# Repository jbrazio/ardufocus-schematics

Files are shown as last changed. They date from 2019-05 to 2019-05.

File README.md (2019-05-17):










**Ardufocus - The most accurate Open Source focus controller.**

Ardufocus is the only OSS/OSH controller supporting **two independent** focusing motors, **high resolution**
mode allowing **sub μm** movements by step, multiple acceleration profiles and it will never forget your
focuser position between restarts.

Ardufocus is a multi repository project:
- [Ardufocus firmware](https://github.com/jbrazio/ardufocus)
- [Ardufocus schematics](https://github.com/jbrazio/ardufocus-schematics)
- [Ardufocus ASCOM IFocuserV3 Driver](https://github.com/jbrazio/ardufocus-ascom)

Ardufocus is licensed under [GNU GPLv3](https://www.gnu.org/licenses/gpl-3.0.en.html). <br />
Ardufocus PCB schematics are licensed under [CC BY-NC-SA 4.0](https://creativecommons.org/licenses/by-nc-sa/4.0/).

----

### For documentation, tutorials and howto visit [ardufocus.com](https://ardufocus.com).

----

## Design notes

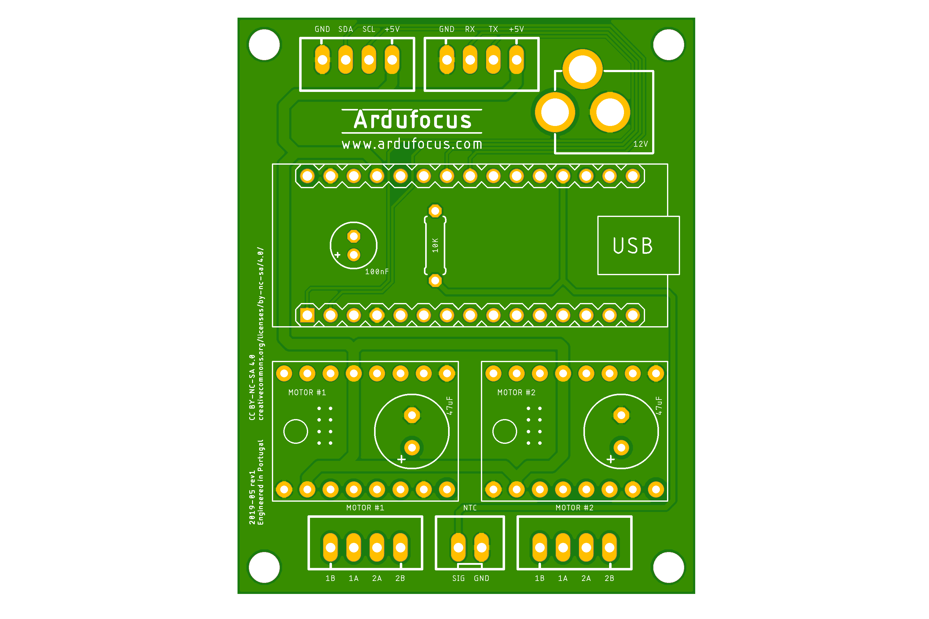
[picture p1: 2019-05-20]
ardufocus/ardufocus-top.png

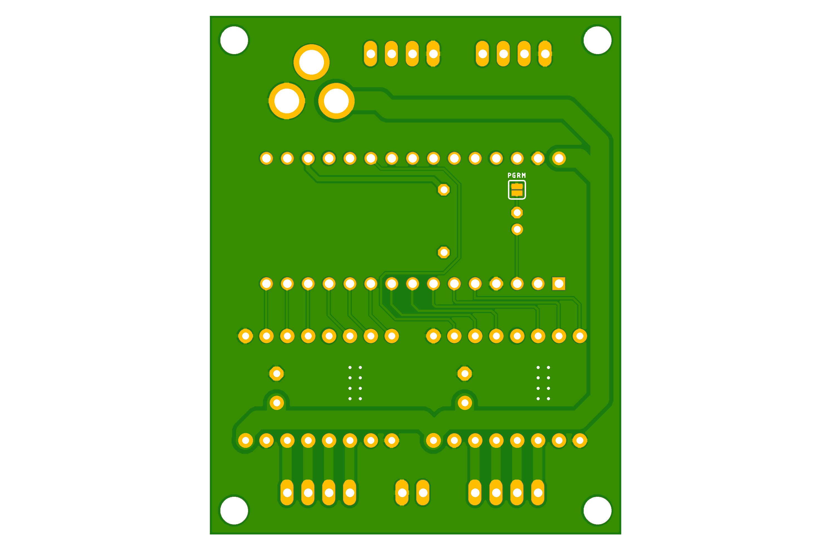
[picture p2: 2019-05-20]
ardufocus/ardufocus-bottom.png

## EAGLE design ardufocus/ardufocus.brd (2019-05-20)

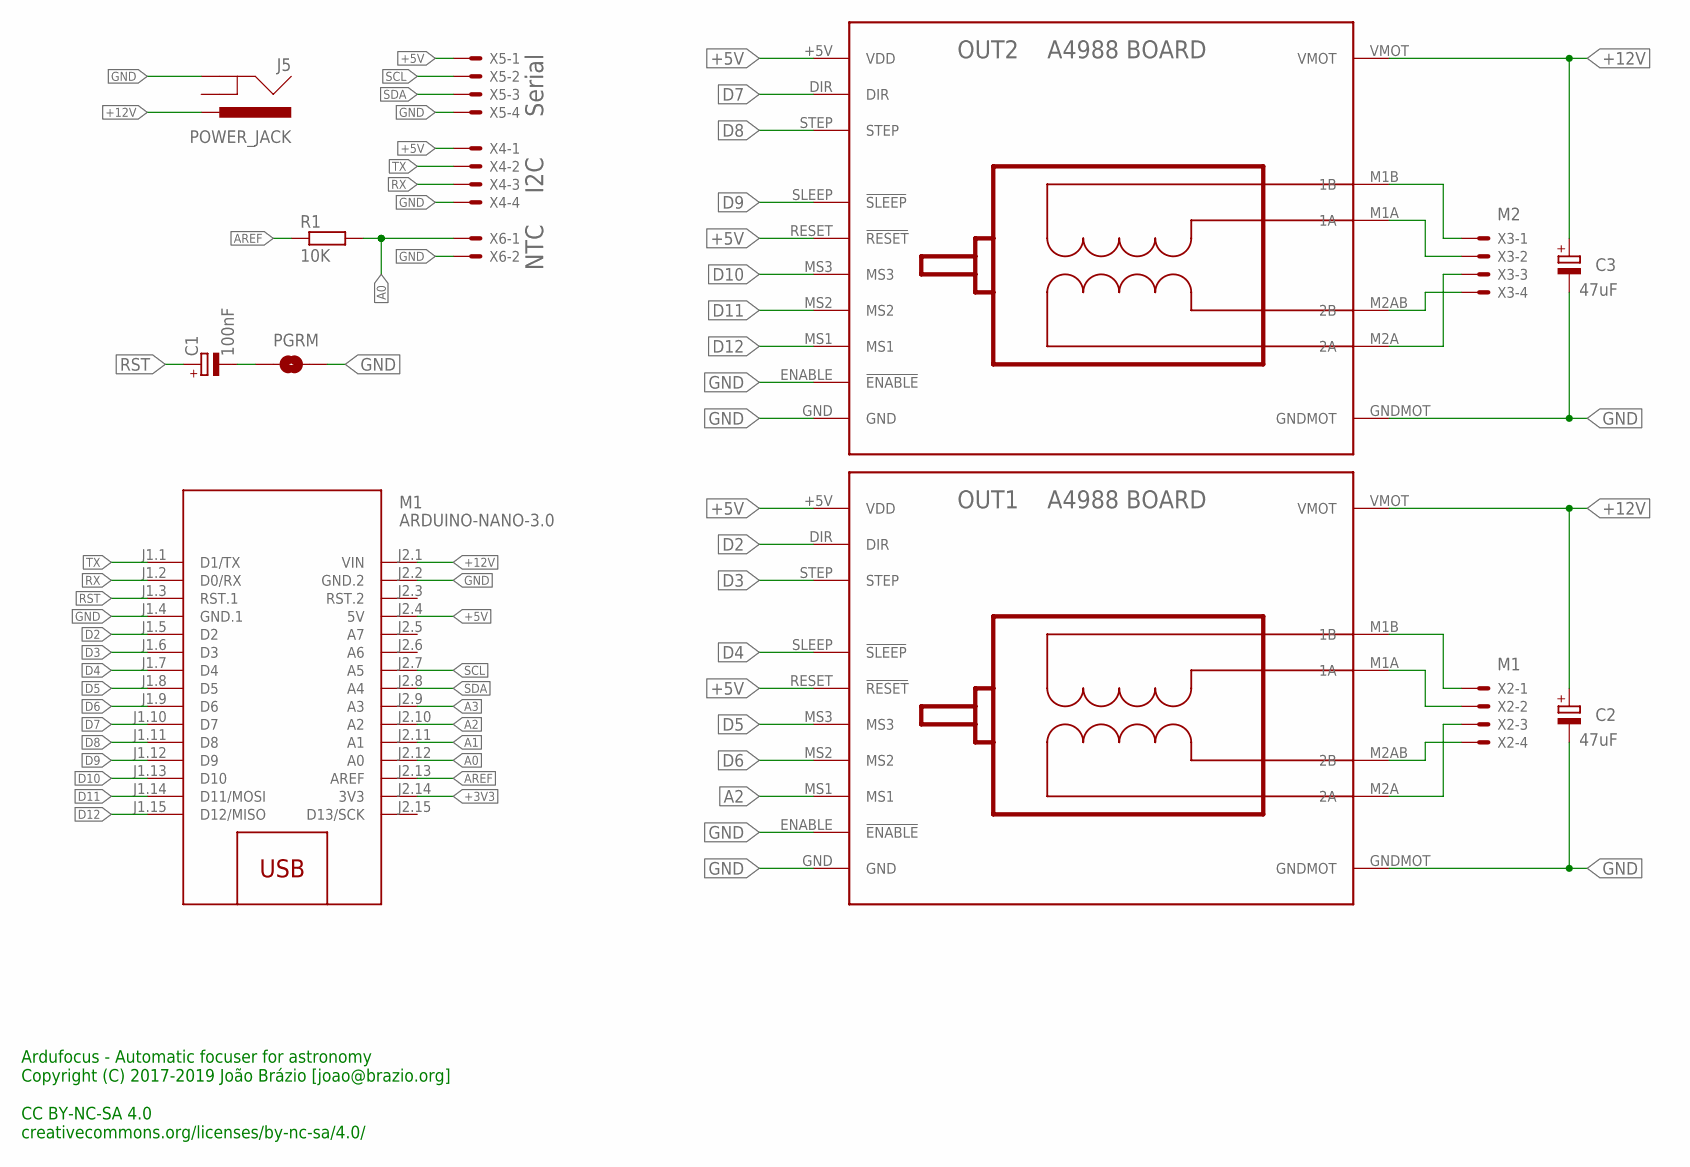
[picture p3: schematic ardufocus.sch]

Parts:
C1: 100nF; E2-5
C2, C3: 47uF; E3,5-8
J5: POWER_JACK; POWER_JACK_PTH
M1: ARDUINO-NANO-3.0
OUT1, OUT2: BOARD_A4988
PGRM: JUMPER-SMT_2_NO_SILK; SMT-JUMPER_2_NO_SILK
R1: 10K; 0207/7
X2, X3, X4, X5: JST-XH-04-PIN-LONG-PAD; JST-XH-04-PACKAGE-LONG-PAD
X6: JST-XH-02-PIN-LONG-PAD; JST-XH-02-PACKAGE-LONG-PAD

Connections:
+3V3: M1.J2.14 (3V3)
+5V: M1.J2.4 (5V), OUT1.+5V (VDD), OUT1.RESET (!RESET), OUT2.+5V (VDD), OUT2.RESET (!RESET), X4.1, X5.1
+12V: C2.+, C3.+, J5.PWR, M1.J2.1 (VIN), OUT1.VMOT, OUT2.VMOT
A0: M1.J2.12 (A0), R1.2, X6.1
A1: M1.J2.11 (A1)
A2: M1.J2.10 (A2), OUT1.MS1
A3: M1.J2.9 (A3)
AREF: M1.J2.13 (AREF), R1.1
D2: M1.J1.5 (D2), OUT1.DIR
D3: M1.J1.6 (D3), OUT1.STEP
D4: M1.J1.7 (D4), OUT1.SLEEP (!SLEEP)
D5: M1.J1.8 (D5), OUT1.MS3
D6: M1.J1.9 (D6), OUT1.MS2
D7: M1.J1.10 (D7), OUT2.DIR
D8: M1.J1.11 (D8), OUT2.STEP
D9: M1.J1.12 (D9), OUT2.SLEEP (!SLEEP)
D10: M1.J1.13 (D10), OUT2.MS3
D11: M1.J1.14 (D11/MOSI), OUT2.MS2
D12: M1.J1.15 (D12/MISO), OUT2.MS1
GND: C2.-, C3.-, J5.GND, M1.J1.4 (GND.1), M1.J2.2 (GND.2), OUT1.ENABLE (!ENABLE), OUT1.GND, OUT1.GNDMOT, OUT2.ENABLE (!ENABLE), OUT2.GND, OUT2.GNDMOT, PGRM.2, X4.4, X5.4, X6.2
unnamed: OUT2.M1B (1B), X3.1
unnamed: C1.-, PGRM.1
unnamed: OUT1.M2A (2A), X2.3
unnamed: OUT2.M1A (1A), X3.2
unnamed: OUT2.M2AB (2B), X3.4
unnamed: OUT1.M1B (1B), X2.1
unnamed: OUT1.M1A (1A), X2.2
unnamed: OUT1.M2AB (2B), X2.4
unnamed: OUT2.M2A (2A), X3.3
RST: C1.+, M1.J1.3 (RST.1)
RX: M1.J1.2 (D0/RX), X4.3
SCL: M1.J2.7 (A5), X5.2
SDA: M1.J2.8 (A4), X5.3
TX: M1.J1.1 (D1/TX), X4.2

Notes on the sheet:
Ardufocus - Automatic focuser for astronomy Copyright (C) 2017-2019 João Brázio [joao@brazio.org] CC BY-NC-SA 4.0 creativecommons.org/licenses/by-nc-sa/4.0/
Serial
I2C
NTC

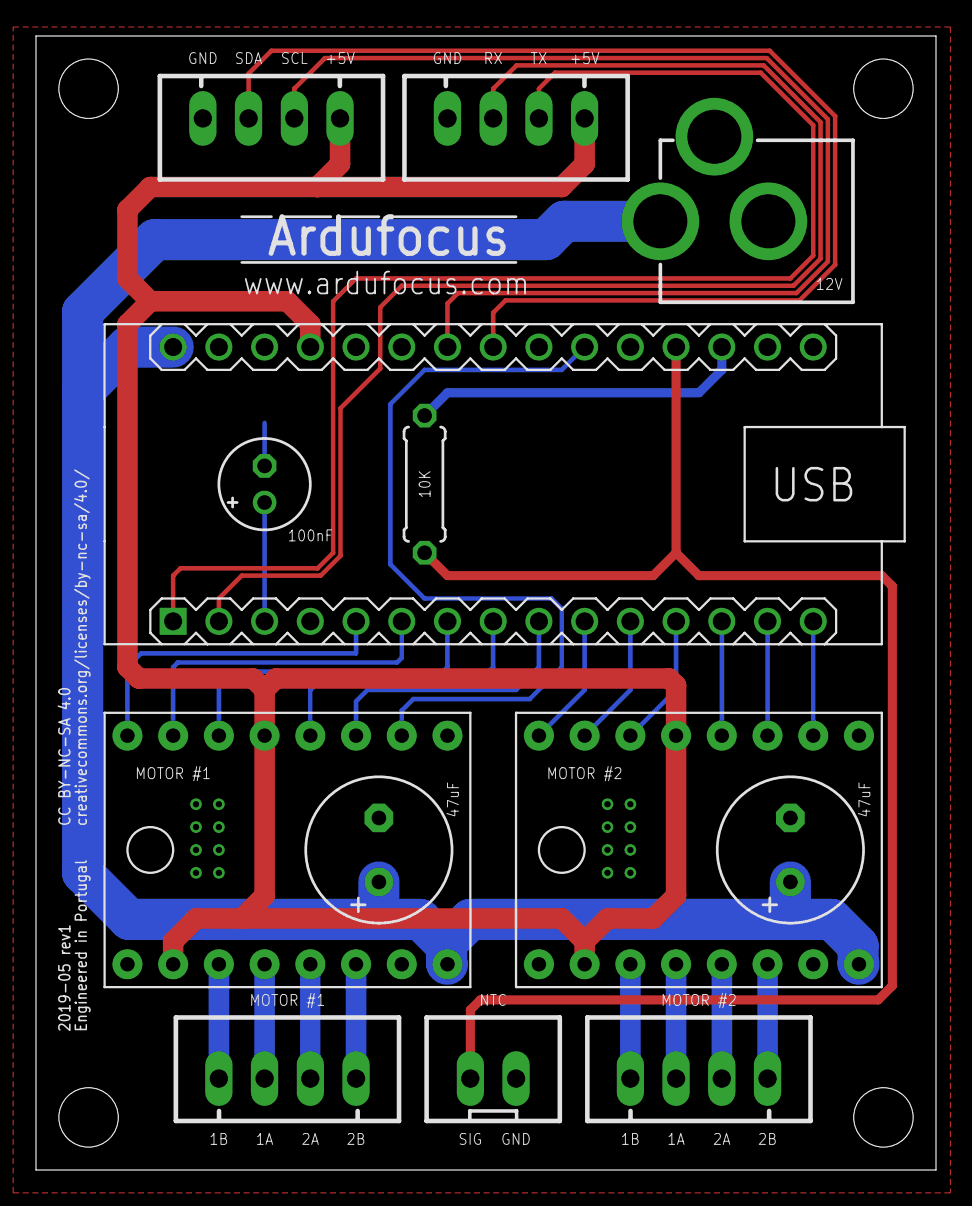
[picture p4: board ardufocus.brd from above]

Board: 2 copper layers, 50.0 x 63.0 mm, 18 parts (1 on the bottom side), 31 nets.

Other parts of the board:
U$1, U$2, U$3, U$4: STAND-OFF

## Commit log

2019-05-17 Project import
    [ardufocus.brd, ardufocus.sch]
2019-05-17 Overall board revision
    [ardufocus.brd, ardufocus.sch]
2019-05-20 Miscellaneous changes
    [ardufocus.brd, ardufocus.sch]
2022-08-04 New PCB layout
    [ardufocus.brd, ardufocus.sch]
2022-08-04 Revert "New PCB layout"
    This reverts commit abb039d9954214917f7d505cd5213ebb6519a360.
    [ardufocus.brd, ardufocus.sch]

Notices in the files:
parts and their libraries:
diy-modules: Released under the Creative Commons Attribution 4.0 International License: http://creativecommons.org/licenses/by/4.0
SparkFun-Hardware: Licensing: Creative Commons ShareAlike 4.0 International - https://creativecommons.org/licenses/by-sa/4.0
